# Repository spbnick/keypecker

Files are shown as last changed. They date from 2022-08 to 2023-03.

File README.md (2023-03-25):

Keypecker
=========

"Keypecker" is a device for measuring key/button switch response speed and
reliability. It uses a stepper motor to (repeatedly) move an actuator rod up
and down, and records the time from the start of the movement to a signal edge
on one or more digital inputs (channels), for each such movement (pass).

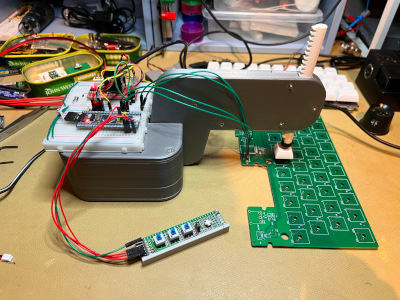
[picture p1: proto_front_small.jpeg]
Prototype front

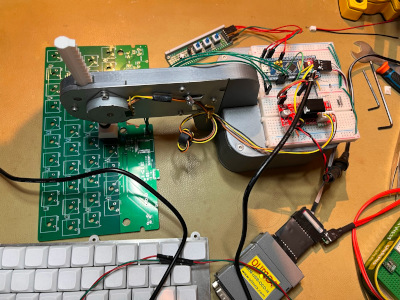
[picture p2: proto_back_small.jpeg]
Prototype back


Keypecker can be used to characterize both physical switches and response of
devices controlled by switches, provided they report events as digital signal
edges.

The device firmware is based on the Zephyr RTOS.

Keypecker is controlled via a TTL-level USART using an interactive shell with
an assortment of supported commands (including stock Zephyr commands):

```
  acquire  :Acquire a timing measurement on all enabled channels for specified
            number of passes (default 1)
  adjust   :Adjust the "current" (default), "top", or "bottom" actuator
            positions interactively
  check    :Check reliability of all-channel triggering between the top and
            bottom positions, over the specified number of passes (default is
            one)
  clear    :Clear screen.
  device   :Device commands
  devmem   :Read/write physical memory
            Usage:
            Read memory at address with optional width:
            devmem address [width]
            Write memory at address with mandatory width and value:
            devmem address <width> <value>
  down     :Move actuator down (n steps)
  get      :Get parameters
  help     :Prints the help message.
  history  :Command history.
  kernel   :Kernel commands
  measure  :Acquire a timing measurement on all enabled channels for specified
            number of passes (default 1), and output "brief" (default), or
            "verbose" results
  off      :Turn off actuator
  on       :Turn on actuator
  print    :Print the last timing measurement in a "brief" (default) or
            "verbose" format
  resize   :Console gets terminal screen size or assumes default in case the
            readout fails. It must be executed after each terminal width
            change to ensure correct text display.
  set      :Set parameters
  setup    :Make sure the actuator is on, and setup top and bottom positions
            specified number of steps (default 1) around the trigger point.
            Verify trigger with specified number of passes (default 2).
  shell    :Useful, not Unix-like shell commands.
  swing    :Move actuator back-n-forth within n steps around current position,
            until interrupted
  tighten  :Move the top and bottom positions within the specified number of
            steps (default 1) around the trigger point. Verify trigger with
            specified number of passes (default 2).
  up       :Move actuator up (n steps)
```

Here's an example session beginning at the power-on, configuring two channels
to detect pressure and release of a directly-connected key switch (Cherry MX
Brown), setting up the top and bottom positions tightly around the trigger
point, verifying that the trigger is reliable through 32 passes, and then
measuring timing of 256 passes (half down, and half up):

```
*** Booting Zephyr OS build zephyr-v3.3.0-474-geead89e7f22d ***

keypecker:~$ resize
keypecker:~$ set ch 0 down rising DOWN
keypecker:~$ set ch 1 up falling UP
keypecker:~$ setup
Actuator is off.
Move the actuator manually to a point above the trigger, and press Enter.
Press Ctrl-C to abort.

Actuator is on.
The current position is the top.
Moving one step down.
Press up and down arrow keys to move the actuator to a point below the
trigger, and press Enter.
Press Ctrl-C to abort.

Bottom position is set.
Tightening around the trigger point.
Press Ctrl-C to abort.

Setup complete.

keypecker:~$ check 32
100%

keypecker:~$ measure 256
                      #0              #1
                    DOWN              UP
-------- --------------- ---------------
    Both           Value           Value
-------- --------------- ---------------
Trigs, %            +100            +100
 Min, us           +2680           +1900
Mean, us           +2800           +1930
 Max, us           +2920           +1960
-------- --------------- ---------------
    Time        Triggers        Triggers
-------- --------------- ---------------
Both, us 0           105 0           128
         |             : |_____________:
    1900 |             : |_____________|
    1963 |             : |             :
    2026 |             : |             :
    2089 |             : |             :
    2152 |             : |             :
    2215 |             : |             :
    2278 |             : |             :
    2341 |             : |             :
    2404 |             : |             :
    2467 |             : |             :
    2530 |             : |             :
    2593 |_            : |             :
    2656 | |___________: |             :
    2719 |_____________| |             :
    2782 |             : |             :
    2845 |             : |             :
    2908 |             : |             :
-------- --------------- ---------------

keypecker:~$
```

The plus `+` signs before the measured numbers indicate overcapture
(bouncing), which is normal for physical switches.

Here's another session. This time a USB keyboard is tested. It signals the
detection of a key pressure/release on the rising edge, and the report of that
event over USB, on the falling edge, using a single wire. That is connected to
two channels - one detecting rising, another - falling edges. After the setup
of the trigger point, and a check of 16 triggers, a measurement of 256 passes
is taken:
```
*** Booting Zephyr OS build zephyr-v3.3.0-474-geead89e7f22d ***

keypecker:~$ resize
keypecker:~$ set ch 0 both rising DETECT
keypecker:~$ set ch 1 both falling REPORT
keypecker:~$ setup
Actuator is off.
Move the actuator manually to a point above the trigger, and press Enter.
Press Ctrl-C to abort.

Actuator is on.
The current position is the top.
Moving one step down.
Press up and down arrow keys to move the actuator to a point below the trigger, and press Enter.
Press Ctrl-C to abort.

Bottom position is set.
Tightening around the trigger point.
Press Ctrl-C to abort.

Setup complete.

keypecker:~$ check 16
100%

keypecker:~$ measure 256
                      #0              #1
                  DETECT          REPORT
-------- --------------- ---------------
    Both           Value           Value
-------- --------------- ---------------
Trigs, %             100             100
 Min, us            6080           12500
Mean, us           14320           20500
 Max, us           22560           28500
-------- --------------- ---------------
    Time        Triggers        Triggers
-------- --------------- ---------------
Both, us 0            49 0           204
         |___________  : |             :
    6080 |           | : |             :
    7481 |           | : |             :
    8882 |           | : |             :
   10283 |           |_: |_____________:
   11684 |        _____| |_____________|
   13085 |_______|     : |             :
   14486 |             : |             :
   15887 |             : |             :
   17288 |             : |             :
   18689 |             : |__           :
   20090 |             : |__|          :
   21491 |             : |             :
   22892 |             : |             :
   24293 |             : |             :
   25694 |             : |             :
   27095 |             : |             :
   28496 |             : |             :
-------- --------------- ---------------

keypecker:~$
```
The data shows that the events are only reported via USB at the interrupt
endpoint polling intervals (set to 9ms).

After (or during) capture the results can be output in verbose mode (somewhat
truncated for brevity):
```
keypecker:~$ print verbose
                      #0              #1
                  DETECT          REPORT
 Up/Down        Time, us        Time, us
-------- --------------- ---------------
    Down           14000           21240
      Up            6840           12540
    Down            8380           12540
      Up            9920           12540
    Down           11440           12540
      Up           12980           20520

(truncated)

    Down            9620           12960
      Up           11160           12960
    Down           12700           12960
      Up           14220           20960
-------- --------------- ---------------
      Up           Value           Value
-------- --------------- ---------------
Trigs, %             100             100
 Min, us            6240           12500
Mean, us           14400           20500
 Max, us           22560           28500
-------- --------------- ---------------
    Down           Value           Value
-------- --------------- ---------------
Trigs, %             100             100
 Min, us            6080           12500
Mean, us           10040           16870
 Max, us           14000           21240
-------- --------------- ---------------
    Both           Value           Value
-------- --------------- ---------------
Trigs, %             100             100
 Min, us            6080           12500
Mean, us           14320           20500
 Max, us           22560           28500
-------- --------------- ---------------
    Time        Triggers        Triggers
-------- --------------- ---------------
  Up, us 0            29 0           102
         |__________   : |             :
    6080 |          |  : |             :
    7481 |         _|  : |             :
    8882 |        |    : |             :
   10283 |        |____: |_____________:
   11684 |     ________| |_____________|
   13085 |____|        : |             :
   14486 |             : |             :
   15887 |             : |             :
   17288 |             : |             :
   18689 |             : |__           :
   20090 |             : |__|          :
   21491 |             : |             :
   22892 |             : |             :
   24293 |             : |             :
   25694 |             : |             :
   27095 |             : |             :
   28496 |             : |             :
-------- --------------- ---------------
Down, us 0            25 0           102
         |___________  : |             :
    6080 |           | : |             :
    7481 |          |__: |             :
    8882 |             | |             :
   10283 |           _|: |_____________:
   11684 |         _|  : |_____________|
   13085 |________|    : |             :
   14486 |             : |             :
   15887 |             : |             :
   17288 |             : |             :
   18689 |             : |__           :
   20090 |             : |__|          :
   21491 |             : |             :
   22892 |             : |             :
   24293 |             : |             :
   25694 |             : |             :
   27095 |             : |             :
   28496 |             : |             :
-------- --------------- ---------------
Both, us 0            49 0           204
         |___________  : |             :
    6080 |           | : |             :
    7481 |           | : |             :
    8882 |           | : |             :
   10283 |           |_: |_____________:
   11684 |        _____| |_____________|
   13085 |_______|     : |             :
   14486 |             : |             :
   15887 |             : |             :
   17288 |             : |             :
   18689 |             : |__           :
   20090 |             : |__|          :
   21491 |             : |             :
   22892 |             : |             :
   24293 |             : |             :
   25694 |             : |             :
   27095 |             : |             :
   28496 |             : |             :
-------- --------------- ---------------

keypecker:~$
```

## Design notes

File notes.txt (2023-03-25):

Commands:
* Disable motor control
	"off"
* Enable motor control
	"on"
* Register the current position as fully pressed (only when enabled)
	"location pressed"
* Register the current position as fully released (only when enabled)
	"location released"
* Move motor down 1 or n steps (only when enabled)
	"down [n]"
* Move motor up 1 or n steps (only when enabled)
	"up [n]"
* Specify how to detect a pressure event (which edge)
	"sense pressure rising"
* Specify how to detect a release event (which edge)
	"sense release falling"

State:
	off
	on
		not moving
		moving

---
We need to be able to tell the actuator which position to go to, and with
which speed. We should also be able to give new instructions before the
previous ones were completed. Finally we should be able to wait until each
instruction is either completed, or aborted/superseded.

We can only have one task at a time, so it makes sense to have one state to
keep. We could have a completion/interruption callback attached to the state.
Then we could have an API that would lock that state, and call interruption
callback when we give it a new task. The timer function would strive to
execute the task and call completion callbacks.
---
TODO: Add an emergency stop button.
---
How about we have a semaphore that's taken for moving the actuator and
returned when moving is done, or aborted?
---

				DISABLED	ENABLED		MOVING
kp_act_get_status		return		return		return
kp_act_set_status(false->true)	-> ENABLED	noop		noop
kp_act_set_status(true->false)	noop		-> DISABLED	-> DISABLED (ABORTED)
kp_act_get_pos			return(last)	return		wait -> return
kp_act_move_(to,by)		return DISABLED	MOVE, return	wait, MOVE, return
kp_act_move_abort		return		return		ABORT, return

MOVE LOCK?

What are we trying to do?

We want to make sure only one thread has control over the actuator, one "procedure".
The command takes control, does its job (moving the actuator,
calibrating/aiming, running a test, etc.), and then releases control.

We want to be able to cancel a command.
	- So, if we want the actuator module to go and do something for us by
	  itself, we need to be able to abort that long-running task. That
	  means we would need to have two-level abort: one level for the
	  actuator library, and one for the command.
	- However, even if we would e.g. try to control the actuator fully, in
	  the command itself, we would still need to have two-level abort: one
	  for the sleep intervals, when we're waiting for the next step, and
	  one for the command itself. So, perhaps, we could live with two
	  levels.
	- E.g. implement locking "actuator control", and provide a function to
	  break that lock, which would make all the functions trying to
	  continue executing with that lock, abort.
We want to be able to reset the robot completely.
	- a simple controller reset would be fine,
	as that would immediately bring "enable" down,
	and release control of the actuator

OK, how about we return a value when enabling the actuator, then use that value
when locking the actuator use, which would return another value.

        off --[on]--> on --[hold]--> held --[move]--> moving
         ^            |^              |^                |
         `----[off]---'`--[release]---'`---[finish]-----'
         ^             ^              |^                |
         `-------------|----[off]-----'`----[abort]-----'
         ^             |                                |
         |             `-------------------[release]----'
         |                                              |
         `-----------------------------------[off]------'

	off --[on: power]--> on --[hold(power): handle]--> held --
	--[move about, read position, etc. (handle)]--> moved --[finish]-->
	held --[release(handle)]-> on --[off(power)]

extern kp_act_power kp_act_on(void);
extern kp_act_pos kp_act_locate(kp_act_power power);
extern kp_act_handle kp_act_hold(kp_act_power power);
extern kp_act_rc kp_act_move(kp_act_handle handle, bool absolute, kp_act_pos pos);
extern void kp_act_abort(kp_act_handle handle);
extern void kp_act_release(kp_act_handle handle);
extern void kp_act_off(kp_act_power power);

Should another module be able to turn off the power without knowing the "power"?
Should we perhaps make the "power" value internal to the kp_act module?
---
What are we trying to do?

* To make it safe to use the actuator from separate threads on a multi-core
  system? Soo...
	* Should a thread be able to "turn on" the actuator if it's already
	  turned on by another thread? The same thread?
	* Should a thread be able to turn off the actuator if it's turned on
	  by another thread?
	* Should a thread be able to cancel a movement requested by another
	  thread?
	  	- We need this for aborting shell commands
	* Should we perhaps provide strongest guarantees for thread
	  separation, and let threads decide how much control they want to
	  share with other threads?
	* There's a difference between protecting threads and giving out
	  the users unique values to handle power ons and actuator movements.

* To make sure that absolute position values are not used across power-ons?
---
We have a single lock for the complete internal state.
We hold the lock while moving to prevent the power being turned off and
another move competing with our move.
We need to be able to abort a move.
	To be able to do that we need to verify that the correct power is
	supplied to the function. To access that we need to acquire a lock.

We need to figure out which pieces of internal state we need when, and how
consistent we need them.
---
Possible operations and exclusivity

init	locate	on	abort
		off
		move

TODO: Check that the actuator module is initialized in all its functions.
	- done
TODO: Consider adding a function checking if a position is valid for a power.
	- not needed anymore, as we don't have "power"

We need to keep all the state locked at first, when starting the movement, and
then unlock the termination flag, so that abortion can happen.

The abortion function needs to verify if the power is on, and if the movement
is running, and then abort.

Timer function:
	With locked state:
		If power is off
			Give movement semaphore
			Stop
		If abort is requested
			Reset abort flag
			Give movement semaphore
			Stop
		Move next step

Move function:
	With locked movement:
		Lock state
		Setup timer
		Unlock state
		Take movement semaphore

We need to prevent two move functions being called at once
---

OK, how do we organize running interactive shell commands?

Shell commands are assigned a kp_cmd_* function each.
The kp_cmd_* function reads and validates arguments, and invokes a library
function specifying which function to run for the actual command body, and
returns with status zero.

The library function sets a shell bypass function which interprets input
sequences, and schedules executing the specified function with another thread,
then returns.

The other thread runs the function, then removes the shell bypass function, to
give control back to the shell.

Can we use setjmp/longjmp to keep the body of actual command inside the
kp_cmd_* function?

So something like this would be nice:

kp_cmd_blah(shell, argc, argv)
{
	/* Parse and validate args */
	...
	/* Install shell bypass, return control to shell */
	YIELD_TO_SHELL;
	/* Run inside separate thread, outside shell */
	/* Return to the thread, which removes shell bypass */
	DONE;
}

Likely won't work, as that would be jumping from one thread's stack to another
thread's stack.

What if instead we had a single generic function save the arguments we're
passed, install the bypass function, schedule execution of the actual
command in another thread, and return to shell. Another thread calls the
function, and then removes the bypass function when it returns.

Or perhaps we can have a macro which installs the bypass function, stores the
current command function address and the arguments and schedules the function
execution in another thread, and returns to the shell. Then another thread
calls the same function but with e.g. a special command name, or maybe a
special shell pointer, and that makes the macro proceed with the function
execution instead. This seems like a good idea.

We can even put the argument validation in front of that macro, so it exits
early. It would be OK to validate and parse arguments again.

How do we implement command termination with Ctrl-C?
OK the input-reading function could scan the input for the Ctrl-C sequence,
and then somehow terminate the command. Maybe the command could pass a
termination callback to kp_shell_cmd_schedule, and that callback would abort
the movement with kp_act_abort(), and set a variable specifying that the
command was aborted?

TODO: Define the move timer inside the move function
	- perhaps won't be needed if we use a timer peripheral for driving
---
Control key inputs:

0x03 - Ctrl-C
0x04 - Ctrl-D
0x1b 0x5b 0x41 - Up
0x1b 0x5b 0x42 - Down
0x1b 0x5b 0x43 - Right
0x1b 0x5b 0x44 - Left
0x0d - Enter
---

So, how should we record our pressure/report times? We can find out which step
triggers the report by calibrating/aiming. Then, before we request moving the
actuator the required number of steps to traverse the report point, in either
direction, we register the current time and the type of the movement
(press/release). After the movement is done, we wait for the report (timestamp
message from GPIO ISR on a message queue?).

OK, we can get a sequence of movement and trigger timestamp pairs in our
testing routine. Now what do we do with that?

We need tests for:
	Detection/report latency for both press and release events
		Take timestamp, move as fast as possible, take signal
		timestamp
		Repeat a bunch of times
		Calculate and report latency minimum, maximum, and averages
	Detection/report reliability/debouncing of both press and release
		Move the actuator with the specified speed
		Wait some time
		Check how many signals we get
		Repeat a bunch of times with varying speed and swing
---
Use Ctrl-C to abort exactly where you are, and Enter to stop nicely (e.g.
return to the start point of "swing").
	- done

FIXME: Swing of a powered-off actuator requires Ctrl-C to exit
	- fixed with a dirty trick
---
Trying to add a shell input reading function

shell_thread
    shell_process
        switch (shell->ctx->state) {
        case SHELL_STATE_ACTIVE:
            shell_process
                state_collect
                    execute
                        exec_cmd
        }

Can we avoid the extra thread?

Nope, we gotta keep processing input

Actually, maybe we can have that special function poll for the RXRDY signal

Posted the failure on GitHub, waiting for advice/comments, continuing with the
hack for now.
---
So, we need to have an STM32 timer started by a rising edge of the "step"
signal, and a capture triggered by the signal we're interested in. If we want
to have more than one input signal, we need more than one timer, or at least
more than one channel. Gotta check that. OK, looks like we can have several
inputs and registers to register the timing. Great!

Now we gotta figure out which pins are available for which.
OK, the pins are listed on page 179 of RM. Default mapping:

CH1:	PA8
CH2:	PA9
CH3:	PA10
CH4:	PA11
ETR:	PA12

Next we'll need to figure out if more configuration is needed on those.
It's likely that it is needed, since there's an USART on PA8-9 by default.

TODO:
* Make sure USART doesn't interfere with the timer
	- switch the pins to "alternate function push-pull" somehow
	- DONE!
* Make the timer start counting and overflow when movement starts
	- Done!

OK, PA11 and PA12 are out of the game, as they're used by USB for D- and D+.
So, we'll have to do with PA8, PA9, PA10. We could use PA10 for trigger, and
PA8 and PA9 for signaling.

Ah, it looks like only the first and the second input channels are connected
to the slave mode controller and can trigger the counter. Well, channel three
can do that too through a XOR gate with all other inputs, but we don't want to
mess with that. So it would be the other way around:

PA8:	Trigger
PA9:	Capture channel 1
PA10:	Capture channel 2

When starting the capture you can specify which channels/how to capture.
Then you can call a function requesting the result when/if it's ready.
---
TODO: Add support for awaiting overcapture for a bounce period
	- Done!
TODO: Retrieve the timer clock rate, like the PWM driver does
      (drivers/pwm/pwm_stm32.c)
---
We can simplify the actuator's interface if we keep the current power
module-side and don't force the caller remember and to provide it.

However, we would still need to expose and to use it for relative movements.
So, maybe we better get rid of the tracked power on altogether.

TODO: Rename kp_pos_* to kp_act_pos_*
	- done
TODO: Initialize GPIO pins outside module initializations
---
So, we need to support a bounce period for capture. It should be separate for
each channel, and should start immediately after the channel is captured.

We should wait for at least the specified period before concluding the
capture, but we can wait for longer, if we're waiting for other channels.

The maximum time we can wait for a channel capture should therefore be the
maximum timer period minus the bounce period.

It seems we need to have a "finish" timer that is started once the last
channel is captured. Should we adjust the auto-reload register then, to point
to the time we need to stop?

We can take the largest captured value across all channels, add the bounce
time to that, and write it to the ARR register.
---
We don't have to maintain the exact minimum bounce time and could take a
little longer. Therefore, we could take our time setting up the timer for
measuring the bounce period.

Once we got all the channels captured, we could stop the timer momentarily,
and shorten the ARR to the current time plus the bounce period, provided that
doesn't exceed the maximum capture time.

Wait, that doesn't let us finish the capture early, right after the timeout,
in case there was nothing captured.

What if we set ARR to the timeout initially, then when the first update
interrupt comes, we shorten the ARR to the bounce time, and on the second
update interrupt we finish.

Eh, maybe let's just keep it this way for now. Timeout of all channels is an
unlikely event, and the bounce time is usually short.

TODO: Use a signal generator to verify bouncing under timer resolution is
      captured. We can use a scope and a real switch for that.
TODO: Use a signal generator to verify bounce-time signals are
      considered timeouts. We can use a scope and a real switch for that.

---
What are we looking for?
The two steps: one immediately before the trigger and one at the trigger. We
might not be able to find them, because they will be too close to the trigger
point. Then we need to find the minimum range of steps where the trigger
happens reliably.

Perhaps we could do each transition a few times to make sure it's reliable,
and back off, it's not.

So, we could have three results for each transition: not triggering,
triggering, triggering unreliably.

We start without the assumption whether the current top-bottom range is
reliably triggering. We test it first, and then proceed.

function check_range(top, bottom, tries):
	for i in range(0, tries):
		move to top
		start capture
		move to bottom
		finish capture
		record result
	return triggered/not triggered/inconclusive

assert kp_act_pos_top < kp_act_pos_bottom
top = None
bottom = None
middle = None
next_top = kp_act_pos_top
next_bottom = kp_act_pos_bottom

forever:
	triggered = check_range(next_top, next_bottom, 3)
	if not triggered:
		# If we tried the top half
		if next_bottom == middle:
			# Try the bottom half
			next_top = middle
			next_bottom = bottom
			continue
		break
	top = next_top
	bottom = next_bottom
	if bottom - top <= 1:
		break
	middle = (top + bottom) / 2
	# Try the top half
	next_top = top
	next_bottom = middle

if not (top and bottom):
	error("No reliable trigger between top and bottom, not narrowed")

if top == kp_act_pos_top and bottom == kp_act_pos_bottom:
	info("The top and bottom positions are already as close as "
		"possible to the trigger point")
kp_act_pos_top = top
kp_act_pos_bottom = bottom

---
We need to handle the situation where we hit exactly the trigger point in one
of the steps and the trigger becomes unstable. We could rectify that by moving
further from the origin boundary. E.g. half way again to the opposite
boundary.
---
So, we need one final push to get actual use out of the device: measuring
timing. We need to make the "measure" command output timing of every pass
(optional), plus the summary (mandatory), for each channel: minimum time,
maximum time, and the average (which one, though? arithmetic mean for the
start? maybe mode as well, rounded to ms?).

TODO: Make k_poll_event_init() accept NULL object with K_POLL_TYPE_IGNORE
TODO: Consider making K_POLL_TYPE_* into an enum for safety.
TODO: Unify format of shell command help messages, including argument
      placement
TODO: Consider testing how fast the keyboard can detect key pressures / how
      many it misses at which speed.
TODO: Figure out if we should check that the top position doesn't also hit the
      trigger.
---
So, something like "measure [<passes> [brief|verbose]]"

And verbose output looking like this:

                      #0              #1
                  DETECT          REPORT
-------- --------------- ---------------
 Up/Down        Time, us        Time, us
-------- --------------- ---------------
    Down           12003           23322
      Up           11449           22334
    Down           12003           23322
      Up           11449           22334
    Down           12003           23322
      Up           11449           22334
    Down           12003           23322
      Up           11449           22334
-------- --------------- ---------------
 Up/Down     Triggers, %     Triggers, %
-------- --------------- ---------------
      Up             100             100
    Down             100             100
 Up&Down             100             100
-------- --------------- ---------------
 Up/Down    Time max, us    Time max, us
-------- --------------- ---------------
      Up           11449           22334
    Down           12003           23322
 Up&Down           11755           22802
-------- --------------- ---------------
 Up/Down    Time min, us    Time min, us
-------- --------------- ---------------
      Up           11449           22334
    Down           12003           23322
 Up&Down           11755           22802
-------- --------------- ---------------
 Up/Down   Time mean, us   Time mean, us
-------- --------------- ---------------
      Up           11449           22334
    Down           12003           23322
 Up&Down           11755           22802
-------- --------------- ---------------
 Up/Down   Time mode, ms   Time mode, ms
-------- --------------- ---------------
      Up              11              22
    Down              12              23
 Up&Down              11              22
-------- --------------- ---------------
Time, us        Triggers        Triggers
-------- --------------- ---------------
    Down 0            50 0            50
   11000 |:___           |              
   11200 |    :_         |              
   11400 |   ___:        |              
   11600 | _:            |              
   11800 |:              |:___          
   12000 |               |    :_        
   12200 |               |   ___:       
   12400 |               | _:           
   12600 |               |:             
-------- --------------- ---------------
      Up 0            50 0            50
   11000 |:___           |              
   11200 |    :_         |              
   11400 |   ___:        |              
   11600 | _:            |              
   11800 |:              |:___          
   12000 |               |    :_        
   12200 |               |   ___:       
   12400 |               | _:           
   12600 |               |:             
-------- --------------- ---------------
    Both 0            50 0            50
         |___	       : |
   11000 |   |         : |              
   11200 |    |_       : |              
   11400 |   ___|      : |              
   11600 | _|          : |              
   11800 ||___         : |:___          
   12000 |    |________: |    :_        
   12200 |         ____| |   ___:       
   12400 |   _____|    : | _:           
   12600 |__|          : |:             
   12600 |             : |:             
   12600 |             : |:             
   12600 |             : |:             
   12600 |             : |:             
   12600 |             : |:             
   12600 |             : |:             
   12600 |             : |:             
-------- --------------- ---------------

Ah, would be nice, but we can't use Unicode characters, because printf equates
bytes to characters. Let's just use words.

FIXME: First capture fails sometimes

A shorter output without breakdown for direction could look like this,
perhaps:

-------- --------------- ---------------
  Metric           Value           Value
-------- --------------- ---------------
Trigs, %             100             100
 Min, us           11449           22334
 Max, us           11755           23322
Mean, us           11623           22750
Mode, us           11623           22750

TODO: Output channel legends at the end of a long output.
TODO: Use TIM1 ETR input for triggering, and enable two more channels

---
TODO: Consider moving all GPIO configuration into main(), as it's the place
	where everything is connected.

So, we still have to wait for a bounce period, when we're moving, even though
we're not capturing any channels, because the bounce from the previous move
could trigger the capture of the next move.

The question is whether we should do the waiting in the capture module or in
the kp_sample() function. In principle, capture doesn't really have to know
anything about moving. It doesn't even have to be invoked along with movement.

OTOH, the kp_sample() function knows exactly when the actuator, and should
expect the contact to bounce, so it is kp_sample() which should take care of
that.

Still OTOH, there's no support for polling for a timer/sleep, so we would have
to have some thread wait that bounce period and then give a semaphore in order
for the poll in kp_sample() to work out that the bounce period has ended.
Perhaps instead we could make the capture module do this for us with certain
inputs. For example, say that if we're invoking a capture with all channels
disabled, it will just wait for the bounce period. And if the code doesn't
want to do that, it should just not invoke the capture. Seems like a good
idea!

Ah, we have a problem: if we're not capturing any channels, we don't know how
long it takes to reach the trigger point, and so just waiting for a bounce
period doesn't work. It might be too short, because it only counts from the
moment of the first capture.

So perhaps we need to tell the users (ourselves :D) that you should have at
least one channel enabled both ways. And as a protection against this
situation we should perhaps make the capture module wait for the full timeout
plus bounce time when capturing with no channels enabled.

---
TODO: Do not waste capture memory, use linear array of capture results with
      dynamic striding according to the number of channels enabled.
      - done
TODO: Do not capture passes (directions) without channels enabled. Adjust
      statistics and histogram generation accordingly.
      - done, most likely
TODO: Store capture parameters and results in a global state, and add a
      separate command outputting previous results according to the same
      output option as taken by the "measure" command. Call it e.g. "display".
      - done
TODO: Add shorter command aliases: "speed", "ch" "adj", "timeout", "bounce".
TODO: Add "setup" command, which sets and tightens the boundaries.
	- done
TODO: Make the "tighten" command smarter and more reliable.
TODO: Use a timer for driving the actuator.
TODO: Make commands accept shortened, but unique string argument values
FIXME: Maximum down times are longer with "measure" without "verbose"
       argument.
	- seems to be gone now

---
OK, assuming that (^^^) is the bounce that gets captured as another rising edge,
and makes the times longer, why is that only captured without verbose output?

Could this be due to interrupt status/timing and the ISR reading the registers
affecting the value written?

OK, so what's the difference? Timing doesn't seem to be it, it's the output to
the shell that makes it behave better in particular, it seems.

So, the hardware manages to sometimes record a bounce, if we don't output to
the shell. Could it be the interference when the serial port is not driven?

TODO: Use a timer for movement
TODO: Implement separate output command
	- done
TODO: Raise the debug pin when a long time is captured on one of the channels
	- not needed, now that the capture discrepancy seems to be fixed
TODO: Figure out why the actuator stops working when the driver board/heatsink
      is flexed
TODO: Refer to enum kp_cap_dir as "Capture direction set"
	- done

Should we count passes which don't capture any channels?
	For tightening?
	For checking?
	For measuring?
Should we actually consider going both ways a "pass" for simplicity?
	If yes, should it be always first down, then up, for simplicity, or
	could it be either?
		Seems like that should be the solution.
		However, this would limit our testing to go always in two
		specific directions, and that may prevent some bugs from
		reproducing.
		So perhaps it's better to keep giving the number of passes.
---
sample - collect -.
                   :--- measure
         display -'

kp_measurement_acquire
kp_measurement_print
kp_measurement_make

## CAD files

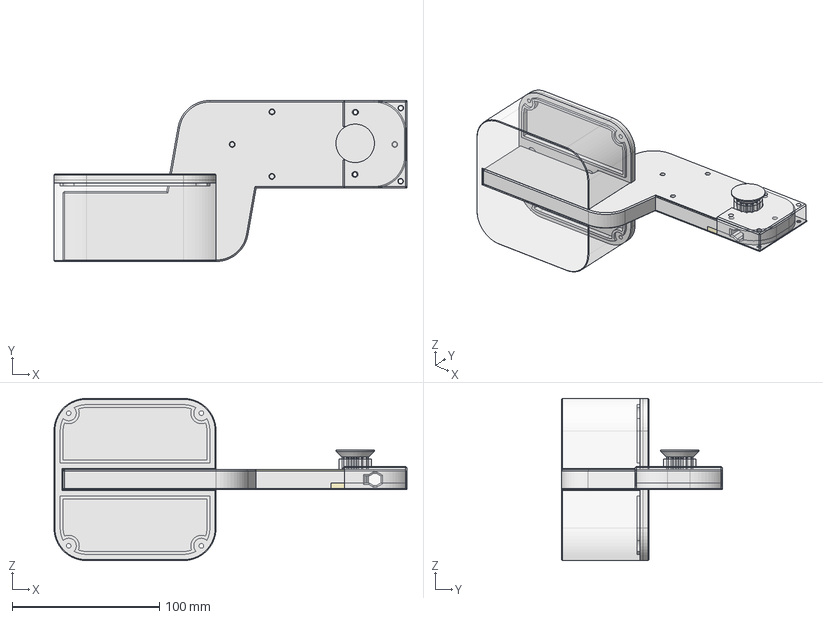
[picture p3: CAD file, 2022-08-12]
keypecker.FCStd
240.0 x 109.5 x 110.2 mm
gear_pusher_old_v2
gear_pusher
motor_heatsink_old
horizontal_arm_body_old
motor_heatsink
weight_body
weight_cap_body
gear
gear_push_guide
ShapeBinder014
arm_slice_1
arm_slice_2
Slice.2

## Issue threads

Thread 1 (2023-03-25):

Support turning off actuator after a configured timeout

spbnick, 2023-03-25:
Keeping the actuator stepper energized requires a lot of power (relatively) and produces a lot of heat, both in the driver and the stepper. Support configuring a timeout after which the actuator is turned off.

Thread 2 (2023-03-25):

Support saving configuration

spbnick, 2023-03-25:
It would be useful to save a lot of configuration parameters, such as channel configuration, timeouts and speeds. Implement saving and loading one or more configurations to/from flesh, using shell commands. Support a command for resetting the device to default configuration. Consider supporting loading (a certain) configuration on boot.

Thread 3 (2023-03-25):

Design the circuit in KiCAD, and produce a bunch of populated PCBs

spbnick, 2023-03-25:
Currently the circuit only exists on a breadboard, in the single prototype. Design a proper (simplified) circuit, possibly using/supporting knock-off STM32F103C8T6 chips, and an actual PCB to be mounted onto the device.

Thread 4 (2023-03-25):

Generalize mechanical and electromechanical design

spbnick, 2023-03-25:
At the moment the design is tuned to the particular piece of stepper heatsink piece I managed to make, and the particular stepper, with particular gear on its shaft. Consider finding a suitable, widely-available (but light) stepper, and redesigning everything around it.

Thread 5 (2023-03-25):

Add emergency stop button

spbnick, 2023-03-25:
Incorporate an emergency stop button into the design. Either a power-cut (preferred), or just the MCU reset button.

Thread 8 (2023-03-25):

Support faster actuator movement with PgUp/PgDn

spbnick, 2023-03-25:
At the moment actuator movement can only be controlled with Up/Down arrow keys, moving the actuator by one step. Support moving the actuator by e.g. ten steps with PgUp/PgDn keys. The problem there are rather involved control sequences coming from the terminal for them, which are hard to parse correctly.

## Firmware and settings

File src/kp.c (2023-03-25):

/** @file
 *  @brief Keypecker main entry point
 */

/*
 * Copyright (c) 2022 Nikolai Kondrashov
 *
 * SPDX-License-Identifier: GPL-2.0-or-later
 */

#include "kp_cap.h"
#include "kp_act.h"
#include "kp_shell.h"
#include "kp_input.h"
#include "kp_sample.h"
#include "kp_meas.h"
#include "kp_misc.h"
#include <stm32_ll_tim.h>
#include <assert.h>
#include <stdlib.h>
#include <sys/types.h>
#include <zephyr/kernel.h>
#include <zephyr/device.h>
#include <zephyr/logging/log.h>
#include <zephyr/drivers/clock_control/stm32_clock_control.h>
#include <zephyr/drivers/gpio.h>
#include <zephyr/drivers/uart.h>
#include <zephyr/shell/shell.h>

/** Devicetree node identifier for the actuator's GPIO port */
#define KP_ACT_GPIO_NODE DT_NODELABEL(gpiob)
/** Devicetree node identifier for the debug GPIO port */
#define KP_DBG_GPIO_NODE DT_NODELABEL(gpioa)

/** Devicetree node identifier for the timer */
#define KP_TIMER_NODE DT_NODELABEL(timers1)

/** The actuator GPIO port device */
static const struct device *kp_act_gpio = DEVICE_DT_GET(KP_ACT_GPIO_NODE);

/** The debug GPIO port device */
static const struct device *kp_dbg_gpio = DEVICE_DT_GET(KP_DBG_GPIO_NODE);

/** The pin for update interrupt debugging */
const gpio_pin_t kp_dbg_pin_update = 3;

/** The base pin for channel capture debugging */
const gpio_pin_t kp_dbg_pin_ch_base = 4;

/** Actuator speed, 0-100% */
static uint32_t kp_act_speed = 100;

/** Top actuator position */
static int32_t kp_act_pos_top = KP_ACT_POS_INVALID;

/** Bottom actuator position */
static int32_t kp_act_pos_bottom = KP_ACT_POS_INVALID;

/** Execute the "on" command */
static int
kp_cmd_on(const struct shell *shell, size_t argc, char **argv)
{
	ARG_UNUSED(argc);
	ARG_UNUSED(argv);
	if (!kp_act_on()) {
		shell_info(shell, "Actuator is already on");
	}
	return 0;
}

SHELL_CMD_REGISTER(on, NULL, "Turn on actuator", kp_cmd_on);

/** Execute the "off" command */
static int
kp_cmd_off(const struct shell *shell, size_t argc, char **argv)
{
	ARG_UNUSED(argc);
	ARG_UNUSED(argv);
	if (kp_act_off()) {
		kp_act_pos_top = KP_ACT_POS_INVALID;
		kp_act_pos_bottom = KP_ACT_POS_INVALID;
	} else {
		shell_info(shell, "Actuator is already off");
	}
	return 0;
}

SHELL_CMD_REGISTER(off, NULL, "Turn off actuator", kp_cmd_off);

/**
 * Parse a non-negative number from a string.
 *
 * @param str	The string to parse the number from.
 * @param pn	Location for the number parsed from the string.
 *
 * @return True if the string was representing a valid non-negative number,
 * 		false otherwise.
 */
static bool
kp_parse_non_negative_number(const char *str, long *pn)
{
	char *end;
	long n;
	n = strtol(str, &end, 10);
	if (*str == '\0' || *end != '\0' || n < 0 || n == LONG_MAX) {
		return false;
	}
	*pn = n;
	return true;
}

/** Execute the "up [steps]" command */
static int
kp_cmd_up(const struct shell *shell, size_t argc, char **argv)
{
	long steps;
	enum kp_act_move_rc rc;
	if (argc >= 2) {
		if (!kp_parse_non_negative_number(argv[1], &steps)) {
			shell_error(shell, "Invalid number of steps: %s",
					argv[1]);
			return 1;
		}
	} else {
		steps = 1;
	}
	rc = kp_act_move_by(-steps, kp_act_speed);
	switch (rc) {
		case KP_ACT_MOVE_RC_OFF:
			shell_error(shell, "Actuator is off, stopping");
			break;
		case KP_ACT_MOVE_RC_ABORTED:
			shell_error(shell, "Aborted");
			break;
		default:
			break;
	}
	return rc != KP_ACT_MOVE_RC_OK;
}

SHELL_CMD_ARG_REGISTER(up, NULL, "Move actuator up (n steps)",
			kp_cmd_up, 1, 1);

/** Execute the "down [steps]" command */
static int
kp_cmd_down(const struct shell *shell, size_t argc, char **argv)
{
	long steps;
	enum kp_act_move_rc rc;
	if (argc >= 2) {
		if (!kp_parse_non_negative_number(argv[1], &steps)) {
			shell_error(shell, "Invalid number of steps: %s",
					argv[1]);
			return 1;
		}
	} else {
		steps = 1;
	}
	rc = kp_act_move_by(steps, kp_act_speed);
	switch (rc) {
		case KP_ACT_MOVE_RC_OFF:
			shell_error(shell, "Actuator is off, stopping");
			break;
		case KP_ACT_MOVE_RC_ABORTED:
			shell_error(shell, "Aborted");
			break;
		default:
			break;
	}
	return rc != KP_ACT_MOVE_RC_OK;
}

SHELL_CMD_ARG_REGISTER(down, NULL, "Move actuator down (n steps)",
			kp_cmd_down, 1, 1);

/**
 * Process input from the bypassed shell of a scheduled command.
 *
 * @param shell Shell instance.
 * @param data  Raw data from transport.
 * @param len   Data length.
 */
static void
kp_input_bypass_cb(const struct shell *shell, uint8_t *data, size_t len)
{
	ARG_UNUSED(shell);
	kp_input_recv(data, len);
}

/** Execute the "swing steps" command */
static int
kp_cmd_swing(const struct shell *shell, size_t argc, char **argv)
{
	/* Poll event indices */
	enum {
		EVENT_IDX_INPUT = 0,
		EVENT_IDX_ACT_FINISH_MOVE,
		EVENT_NUM
	};
	long steps;
	enum kp_act_move_rc rc;
	enum kp_input_msg msg;
	int32_t start_pos;
	struct k_poll_event events[EVENT_NUM];

	/* Parse arguments */
	assert(argc == 2 || argc == (size_t)SSIZE_MAX + 2);
	if (!kp_parse_non_negative_number(argv[1], &steps) || steps == 0) {
		shell_error(shell, "Invalid number of steps: %s",
				argv[1]);
		return 1;
	}

	/* Check for power */
	if (kp_act_is_off()) {
		shell_error(shell, "Actuator is off, aborting");
		return 1;
	}

	/* Return to the shell and restart in an input-diverted thread */
	KP_SHELL_YIELD(kp_cmd_swing, kp_input_bypass_cb);
	kp_input_reset();

	/* Remember the start position */
	start_pos = kp_act_locate();

	/* Initialize events */
	kp_input_get_event_init(&events[EVENT_IDX_INPUT]);
	kp_act_finish_move_event_init(&events[EVENT_IDX_ACT_FINISH_MOVE]);

	/* Move */
	shell_print(shell, "Swinging, press Enter to stop, Ctrl-C to abort");
	rc = kp_act_move_by(steps / 2, kp_act_speed);
	bool finished = false;
	while (rc == KP_ACT_MOVE_RC_OK && !finished) {
		bool moved = false;
		steps = -steps;
		kp_act_start_move_by(steps, kp_act_speed);
		while (rc == KP_ACT_MOVE_RC_OK && !moved) {
			while (k_poll(events, ARRAY_SIZE(events),
				      K_FOREVER) != 0);

			if (events[EVENT_IDX_INPUT].state) {
				while (kp_input_get(&msg, K_FOREVER) != 0);
				if (msg == KP_INPUT_MSG_ABORT) {
					kp_act_abort();
				} else if (msg == KP_INPUT_MSG_ENTER) {
					finished = true;
				}
			}

			if (events[EVENT_IDX_ACT_FINISH_MOVE].state) {
				rc = kp_act_finish_move(K_FOREVER);
				moved = (rc == KP_ACT_MOVE_RC_OK);
			}

			/* Reset event state */
			for (size_t i = 0; i < ARRAY_SIZE(events); i++) {
				events[i].state = K_POLL_STATE_NOT_READY;
			}
		}
	}

	if (finished && rc == KP_ACT_MOVE_RC_OK) {
		/* Return to the start position */
		rc = kp_act_move_to(start_pos, kp_act_speed);
	}

	/* Report error, if any */
	if (rc == KP_ACT_MOVE_RC_ABORTED) {
		shell_error(shell, "Aborted");
	} else if (rc == KP_ACT_MOVE_RC_OFF) {
		shell_error(shell, "Actuator is off, stopping");
	}
	return rc != KP_ACT_MOVE_RC_OK;
}

SHELL_CMD_ARG_REGISTER(swing, NULL,
			"Move actuator back-n-forth within n steps around "
			"current position, until interrupted",
			kp_cmd_swing, 2, 0);

/**
 * Adjust the value of the specified actuator position variable interactively.
 *
 * @param ppos	Location for the position variable to adjust.
 * 		If NULL, or if the value is invalid, the adjustment starts
 * 		from the current position. If NULL, the final position is not
 * 		stored. Only written to after a successful adjustment.
 * @param min	The minimum position to limit adjustment to, less than or
 *		equal to max. Or KP_ACT_POS_INVALID, meaning KP_ACT_POS_MIN.
 * @param max	The maximum position to limit adjustment to, greater than or
 *		equal to min. Or KP_ACT_POS_INVALID, meaning KP_ACT_POS_MAX.
 * @param speed	The speed with which to move, 0-100%.
 *
 * @return A movement result code, excluding KP_ACT_MOVE_TIMEOUT.
 */
static enum kp_act_move_rc
kp_adjust(int32_t *ppos, int32_t min, int32_t max, uint32_t speed)
{
	int32_t pos = (ppos == NULL) ? KP_ACT_POS_INVALID : *ppos;
	enum kp_act_move_rc rc;
	enum kp_input_msg msg;

	if (!kp_act_pos_is_valid(min)) {
		min = KP_ACT_POS_MIN;
	}
	if (!kp_act_pos_is_valid(max)) {
		max = KP_ACT_POS_MAX;
	}

	assert(min <= max);

	if (!kp_act_pos_is_valid(pos)) {
		pos = kp_act_locate();
		if (!kp_act_pos_is_valid(pos)) {
			return KP_ACT_MOVE_RC_OFF;
		}
	}

	/* Bring the variable within the allowed range */
	pos = CLAMP(pos, min, max);

	/* Move to the position in the variable */
	rc = kp_act_move_to(pos, speed);
	if (rc != KP_ACT_MOVE_RC_OK) {
		return rc;
	}

	/* Adjust the position within the allowed range until confirmed */
	do {
		while (kp_input_get(&msg, K_FOREVER) != 0);
		if (msg == KP_INPUT_MSG_UP || msg == KP_INPUT_MSG_DOWN) {
			pos += (msg == KP_INPUT_MSG_DOWN) ? 1 : -1;
			pos = CLAMP(pos, min, max);
			rc = kp_act_move_to(pos, speed);
			if (rc != KP_ACT_MOVE_RC_OK) {
				return rc;
			}
		} else if (msg == KP_INPUT_MSG_ABORT) {
			return KP_ACT_MOVE_RC_ABORTED;
		}
	} while (msg != KP_INPUT_MSG_ENTER);

	/* Output the new position, if requested */
	if (ppos != NULL) {
		*ppos = pos;
	}

	return KP_ACT_MOVE_RC_OK;
}

/** Execute the "adjust" command */
static int
kp_cmd_adjust(const struct shell *shell, size_t argc, char **argv)
{
	int32_t start_pos;
	const char *arg;
	int32_t min = KP_ACT_POS_MIN;
	int32_t max = KP_ACT_POS_MAX;
	int32_t *ppos = NULL;
	enum kp_act_move_rc rc;

	ARG_UNUSED(argc);
	ARG_UNUSED(argv);

	/* Get the start position and check for power */
	if (!kp_act_pos_is_valid(start_pos = kp_act_locate())) {
		shell_error(shell, "Actuator is off, aborting");
		return 1;
	}

	/* Return to the shell and restart in an input-diverted thread */
	KP_SHELL_YIELD(kp_cmd_adjust, kp_input_bypass_cb);
	kp_input_reset();

	/* Parse the optional argument */
	if (argc > 1) {
		arg = argv[1];
		if (kp_strcasecmp(arg, "top") == 0) {
			ppos = &kp_act_pos_top;
			if (kp_act_pos_is_valid(kp_act_pos_bottom)) {
				max = kp_act_pos_bottom - 1;
			}
		} else if (kp_strcasecmp(arg, "bottom") == 0) {
			if (kp_act_pos_is_valid(kp_act_pos_top)) {
				min = kp_act_pos_top + 1;
			}
			ppos = &kp_act_pos_bottom;
		} else if (kp_strcasecmp(arg, "current") != 0) {
			shell_error(
				shell,
				"Invalid position name "
				"(current/top/bottom expected): %s",
				arg
			);
			return 1;
		}
	}

	/* Adjust */
	shell_print(shell,
		    "Press up and down arrow keys to move the actuator.");
	shell_print(shell, "Press Enter to stop, Ctrl-C to abort.");
	rc = kp_adjust(ppos, min, max, kp_act_speed);

	/* Report error, if any */
	if (rc == KP_ACT_MOVE_RC_ABORTED) {
		shell_error(shell, "Aborted");
		return rc;
	} else if (rc == KP_ACT_MOVE_RC_OFF) {
		shell_error(shell, "Actuator is off, stopping");
		return rc;
	}

	/* Stop, if changing the current position */
	if (ppos == NULL) {
		return 0;
	}

	/* Try to return to the start position */
	switch (kp_act_move_to(start_pos, kp_act_speed)) {
		case KP_ACT_MOVE_RC_OK:
			break;
		case KP_ACT_MOVE_RC_ABORTED:
			shell_warn(
				shell,
				"Moving back to the start position "
				"was aborted"
			);
			break;
		case KP_ACT_MOVE_RC_OFF:
			shell_warn(
				shell,
				"Couldn't move back to the start "
				"position - actuator is off"
			);
			break;
		default:
			shell_error(
				shell,
				"Unexpected error moving back to the "
				"start position"
			);
			break;
	}

	return 0;
}

SHELL_CMD_ARG_REGISTER(adjust, NULL,
		       "Adjust the \"current\" (default), \"top\", "
		       "or \"bottom\" actuator positions interactively",
		       kp_cmd_adjust, 1, 1);

/** Execute the "set speed <percentage>" command */
static int
kp_cmd_set_speed(const struct shell *shell, size_t argc, char **argv)
{
	long speed;

	assert(argc == 2);

	if (!kp_parse_non_negative_number(argv[1], &speed) || speed > 100) {
		shell_error(
			shell,
			"Invalid speed percentage (expecting 0-100): %s",
			argv[1]
		);
		return 1;
	}
	kp_act_speed = (uint32_t)speed;
	return 0;
}

/** Execute the "set top" command */
static int
kp_cmd_set_top(const struct shell *shell, size_t argc, char **argv)
{
	int32_t pos;
	ARG_UNUSED(argc);
	ARG_UNUSED(argv);
	pos = kp_act_locate();
	if (!kp_act_pos_is_valid(pos)) {
		shell_error(shell, "Actuator is off, position not set");
		return 1;
	}
	if (kp_act_pos_is_valid(kp_act_pos_bottom) &&
			pos >= kp_act_pos_bottom) {
		shell_error(shell, "Position not above bottom, not set");
		return 1;
	}
	kp_act_pos_top = pos;
	return 0;
}

/** Execute the "set bottom" command */
static int
kp_cmd_set_bottom(const struct shell *shell, size_t argc, char **argv)
{
	int32_t pos;
	ARG_UNUSED(argc);
	ARG_UNUSED(argv);
	pos = kp_act_locate();
	if (!kp_act_pos_is_valid(pos)) {
		shell_error(shell, "Actuator is off, position not set");
		return 1;
	}
	if (kp_act_pos_is_valid(kp_act_pos_top) &&
			pos <= kp_act_pos_top) {
		shell_error(shell, "Position not below top, not set");
		return 1;
	}
	kp_act_pos_bottom = pos;
	return 0;
}

/** Capture configuration */
static struct kp_cap_conf kp_cap_conf;

/** Execute the
 * "set ch <idx> none/up/down/both [rising/falling [<name>]]"
 * command */
static int
kp_cmd_set_ch(const struct shell *shell, size_t argc, char **argv)
{
	long idx;
	const char *arg;
	struct kp_cap_ch_conf conf;
	assert(argc >= 3);
	assert(argc <= 5);

	/* Parse channel index */
	arg = argv[1];
	if (!kp_parse_non_negative_number(arg, &idx) ||
			idx >= ARRAY_SIZE(kp_cap_conf.ch_list)) {
		shell_error(
			shell,
			"Invalid channel index (0-%zu expected): %s",
			ARRAY_SIZE(kp_cap_conf.ch_list) - 1,
			arg
		);
		return 1;
	}

	/* Read current state */
	conf = kp_cap_conf.ch_list[idx];

	/* Parse capture directions, if specified */
	if (argc >= 3) {
		arg = argv[2];
		if (!kp_cap_dirs_from_str(arg, &conf.dirs)) {
			shell_error(
				shell,
				"Invalid capture directions "
				"(none/up/down/both expected): %s",
				arg
			);
			return 1;
		}
	}

	/* Parse capture edge, if specified */
	if (argc >= 4) {
		arg = argv[3];
		if (kp_strcasecmp(arg, "rising") == 0) {
			conf.rising = true;
		} else if (kp_strcasecmp(arg, "falling") == 0) {
			conf.rising = false;
		} else {
			shell_error(
				shell,
				"Invalid capture edge "
				"(rising/falling expected): %s",
				arg
			);
			return 1;
		}
	}

	/* Read name, if specified */
	if (argc >= 5) {
		arg = argv[4];
		if (strlen(arg) >= sizeof(conf.name)) {
			shell_error(
				shell,
				"Channel name too long "
				"(%zu > %zu expected characters): %s",
				strlen(arg),
				sizeof(conf.name) - 1,
				arg
			);
			return 1;
		}
		strcpy(conf.name, arg);
	}

	/* Store the parameters */
	kp_cap_conf.ch_list[idx] = conf;

	return 0;
}

/** Execute the "set timeout <us>" command */
static int
kp_cmd_set_timeout(const struct shell *shell, size_t argc, char **argv)
{
	long timeout_us;

	assert(argc == 2);

	if (!kp_parse_non_negative_number(argv[1], &timeout_us)) {
		shell_error(shell, "Invalid timeout: %s", argv[1]);
		return 1;
	}
	if ((uint32_t)timeout_us + kp_cap_conf.bounce_us >=
	    KP_CAP_TIME_MAX_US) {
		shell_error(
			shell,
			"Timeout plus bounce time exceed "
			"maximum capture time: %ld + %u >= %u",
			timeout_us, kp_cap_conf.bounce_us, KP_CAP_TIME_MAX_US
		);
		return 1;
	};
	kp_cap_conf.timeout_us = (uint32_t)timeout_us;
	return 0;
}

/** Execute the "set bounce <us>" command */
static int
kp_cmd_set_bounce(const struct shell *shell, size_t argc, char **argv)
{
	long bounce_us;

	assert(argc == 2);

	if (!kp_parse_non_negative_number(argv[1], &bounce_us)) {
		shell_error(shell, "Invalid bounce time: %s", argv[1]);
		return 1;
	}
	if (kp_cap_conf.timeout_us + (uint32_t)bounce_us >=
	    KP_CAP_TIME_MAX_US) {
		shell_error(
			shell,
			"Bounce time plus timeout exceed "
			"maximum capture time: %ld + %u >= %u",
			bounce_us, kp_cap_conf.timeout_us, KP_CAP_TIME_MAX_US
		);
		return 1;
	};
	kp_cap_conf.bounce_us = (uint32_t)bounce_us;
	return 0;
}

SHELL_STATIC_SUBCMD_SET_CREATE(set_subcmds,
	SHELL_CMD_ARG(speed, NULL,
			"Set speed: <percentage>",
			kp_cmd_set_speed, 2, 0),
	SHELL_CMD(top, NULL, "Register current position as the top",
			kp_cmd_set_top),
	SHELL_CMD(bottom, NULL, "Register current position as the bottom",
			kp_cmd_set_bottom),
	SHELL_CMD_ARG(ch, NULL,
			"Set channel configuration: "
			"<idx> none/up/down/both [rising/falling [<name>]]",
			kp_cmd_set_ch, 3, 2),
	SHELL_CMD_ARG(timeout, NULL,
			"Set capture timeout: <us>",
			kp_cmd_set_timeout, 2, 0),
	SHELL_CMD_ARG(bounce, NULL,
			"Set bounce time: <us>",
			kp_cmd_set_bounce, 2, 0),
	SHELL_SUBCMD_SET_END
);

SHELL_CMD_REGISTER(set, &set_subcmds,
			"Set parameters", NULL);

/** Execute the "get speed" command */
static int
kp_cmd_get_speed(const struct shell *shell, size_t argc, char **argv)
{
	ARG_UNUSED(argc);
	ARG_UNUSED(argv);
	shell_print(shell, "%u%%", kp_act_speed);
	return 0;
}

/** Execute the "get top" command */
static int
kp_cmd_get_top(const struct shell *shell, size_t argc, char **argv)
{
	enum kp_act_move_rc rc;
	ARG_UNUSED(argc);
	ARG_UNUSED(argv);
	if (!kp_act_pos_is_valid(kp_act_pos_top)) {
		shell_error(shell, "Top position not set, not moving");
		return 1;
	}
	rc = kp_act_move_to(kp_act_pos_top, kp_act_speed);
	if (rc == KP_ACT_MOVE_RC_ABORTED) {
		shell_error(shell, "Aborted");
	} else if (rc == KP_ACT_MOVE_RC_OFF) {
		shell_error(shell, "Actuator is off, stopping");
	}
	return rc != KP_ACT_MOVE_RC_OK;
}

/** Execute the "get bottom" command */
static int
kp_cmd_get_bottom(const struct shell *shell, size_t argc, char **argv)
{
	enum kp_act_move_rc rc;
	ARG_UNUSED(argc);
	ARG_UNUSED(argv);
	if (!kp_act_pos_is_valid(kp_act_pos_bottom)) {
		shell_error(shell, "Bottom position not set, not moving");
		return 1;
	}
	rc = kp_act_move_to(kp_act_pos_bottom, kp_act_speed);
	if (rc == KP_ACT_MOVE_RC_ABORTED) {
		shell_error(shell, "Aborted");
	} else if (rc == KP_ACT_MOVE_RC_OFF) {
		shell_error(shell, "Actuator is off, stopping");
	}
	return rc != KP_ACT_MOVE_RC_OK;
}

/** Execute the "get ch <idx>" command */
static int
kp_cmd_get_ch(const struct shell *shell, size_t argc, char **argv)
{
	long idx;
	const char *arg;
	const struct kp_cap_ch_conf *conf;

	assert(argc == 2);

	/* Parse channel index */
	arg = argv[1];
	if (!kp_parse_non_negative_number(arg, &idx) ||
			idx >= ARRAY_SIZE(kp_cap_conf.ch_list)) {
		shell_error(
			shell,
			"Invalid channel index (0-%zu expected): %s",
			ARRAY_SIZE(kp_cap_conf.ch_list) - 1,
			arg
		);
		return 1;
	}

	/* Output channel configuration */
	conf = &kp_cap_conf.ch_list[idx];
	shell_print(shell, "%s %s %s",
			kp_cap_dirs_to_lcstr(conf->dirs),
			(conf->rising ? "rising" : "falling"),
			conf->name);
	return 0;
}

/** Execute the "get timeout" command */
static int
kp_cmd_get_timeout(const struct shell *shell, size_t argc, char **argv)
{
	ARG_UNUSED(argc);
	ARG_UNUSED(argv);
	shell_print(shell, "%u us", kp_cap_conf.timeout_us);
	return 0;
}

/** Execute the "get bounce" command */
static int
kp_cmd_get_bounce(const struct shell *shell, size_t argc, char **argv)
{
	ARG_UNUSED(argc);
	ARG_UNUSED(argv);
	shell_print(shell, "%u us", kp_cap_conf.bounce_us);
	return 0;
}

SHELL_STATIC_SUBCMD_SET_CREATE(get_subcmds,
	SHELL_CMD(speed, NULL,
			"Get speed percentage",
			kp_cmd_get_speed),
	SHELL_CMD(top, NULL, "Restore the top position",
			kp_cmd_get_top),
	SHELL_CMD(bottom, NULL, "Restore the bottom position",
			kp_cmd_get_bottom),
	SHELL_CMD_ARG(ch, NULL,
			"Get channel configuration: "
			"<idx> -> none/up/down/both rising/falling <name>",
			kp_cmd_get_ch, 2, 0),
	SHELL_CMD(timeout, NULL,
			"Get capture timeout, us",
			kp_cmd_get_timeout),
	SHELL_CMD(bounce, NULL,
			"Get bounce time, us",
			kp_cmd_get_bounce),
	SHELL_SUBCMD_SET_END
);

SHELL_CMD_REGISTER(get, &get_subcmds,
			"Get parameters", NULL);
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
void
main(void)
{
	const struct device *dev;
	size_t i;

	/* Check shell UART is ready */
	dev = DEVICE_DT_GET(DT_CHOSEN(zephyr_shell_uart));
	if (!device_is_ready(dev)) {
		return;
	}

	/* Initialize the shell extensions */
	kp_shell_init();

	/*
	 * Initialize GPIO pins
	 */
	if (!device_is_ready(kp_act_gpio)) {
		return;
	}
	if (!device_is_ready(kp_dbg_gpio)) {
		return;
	}
	gpio_pin_configure(kp_dbg_gpio, kp_dbg_pin_update,
				GPIO_PUSH_PULL | GPIO_OUTPUT_LOW);

	/*
	 * Initialize the actuator
	 */
	kp_act_init(kp_act_gpio, /* disable */ 3, /* dir */ 8, /* step */ 9);

	/*
	 * Set default capture configuration
	 */
	kp_cap_conf.timeout_us = 1000000;
	kp_cap_conf.bounce_us = 50000;
	for (i = 0; i < ARRAY_SIZE(kp_cap_conf.ch_list); i++) {
		kp_cap_conf.ch_list[i] = (struct kp_cap_ch_conf){
			.dirs = KP_CAP_DIRS_NONE,
			.rising = true,
			.name = {0},
		};
	}

	/*
	 * Configure capturer debug output
	 */
	struct kp_cap_dbg_conf cap_dbg_conf = {
		.gpio = kp_dbg_gpio,
		.update_pin = kp_dbg_pin_update,
	};
	for (i = 0; i < ARRAY_SIZE(cap_dbg_conf.cap_pin_list); i++) {
		gpio_pin_configure(cap_dbg_conf.gpio, kp_dbg_pin_ch_base + i,
					GPIO_PUSH_PULL | GPIO_OUTPUT_LOW);
		cap_dbg_conf.cap_pin_list[i] = kp_dbg_pin_ch_base + i;
	}

	/*
	 * Initialize the capturer
	 */
	const struct device *clk = DEVICE_DT_GET(STM32_CLOCK_CONTROL_NODE);
	struct stm32_pclken pclken = {
		.bus = DT_CLOCKS_CELL(KP_TIMER_NODE, bus),
		.enr = DT_CLOCKS_CELL(KP_TIMER_NODE, bits)
	};
	if (!device_is_ready(clk)) {
		return;
	}
	if (clock_control_on(clk, (clock_control_subsys_t *)&pclken) < 0) {
		return;
	}
	IRQ_CONNECT(DT_IRQ_BY_NAME(KP_TIMER_NODE, trgcom, irq),
		    DT_IRQ_BY_NAME(KP_TIMER_NODE, trgcom, priority),
		    kp_cap_isr, NULL, 0);
	irq_enable(DT_IRQ_BY_NAME(KP_TIMER_NODE, trgcom, irq));
	IRQ_CONNECT(DT_IRQ_BY_NAME(KP_TIMER_NODE, up, irq),
		    DT_IRQ_BY_NAME(KP_TIMER_NODE, up, priority),
		    kp_cap_isr, NULL, 0);
	irq_enable(DT_IRQ_BY_NAME(KP_TIMER_NODE, up, irq));
	IRQ_CONNECT(DT_IRQ_BY_NAME(KP_TIMER_NODE, cc, irq),
		    DT_IRQ_BY_NAME(KP_TIMER_NODE, cc, priority),
		    kp_cap_isr, NULL, 0);
	irq_enable(DT_IRQ_BY_NAME(KP_TIMER_NODE, cc, irq));
	kp_cap_init((TIM_TypeDef *)DT_REG_ADDR(KP_TIMER_NODE), &cap_dbg_conf);
}

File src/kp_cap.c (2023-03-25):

/** @file
 *  @brief Keypecker capturer
 */

/*
 * Copyright (c) 2022 Nikolai Kondrashov
 *
 * SPDX-License-Identifier: GPL-2.0-or-later
 */

#include "kp_cap.h"
#include "kp_misc.h"
#include <string.h>

/** Masks for the channels available for capture */
static const uint32_t kp_cap_ch_mask_list[KP_CAP_CH_NUM] = {
	LL_TIM_CHANNEL_CH2,
	LL_TIM_CHANNEL_CH3,
};

/** Capture interrupt-enabling/interrupt-flag masks for each channel */
/* NOTE: Assuming SR bits match DIER bits */
static const uint32_t kp_cap_ch_ccif_mask_list[KP_CAP_CH_NUM] = {
	TIM_SR_CC2IF,
	TIM_SR_CC3IF,
};

/** Overcapture flag masks for each channel */
static const uint32_t kp_cap_ch_ccof_mask_list[KP_CAP_CH_NUM] = {
	TIM_SR_CC2OF,
	TIM_SR_CC3OF,
};

/** Offset of the captured-value register for each channel, bytes */
static const size_t kp_cap_ch_ccr_offset_list[KP_CAP_CH_NUM] = {
	offsetof(TIM_TypeDef, CCR2),
	offsetof(TIM_TypeDef, CCR3),
};

/** The timer to use for capture */
static TIM_TypeDef* kp_cap_timer = NULL;

/** Debugg output configuration */
struct kp_cap_dbg_conf kp_cap_dbg_conf;

/** The semaphore signaling a capture can be started */
static K_SEM_DEFINE(kp_cap_available, 1, 1);

/** The capture interrupt mask for all channels to be captured */
static uint32_t kp_cap_ch_ccif_mask;

/** The maximum number of ticks to await capture of all channels */
static uint32_t kp_cap_timeout_ticks;

/** The minimum number of ticks to wait for a channel to bounce */
static uint32_t kp_cap_bounce_ticks;

/** The capture abort flag */
static volatile bool kp_cap_aborted;

/** The semaphore signaling a capture is done */
static K_SEM_DEFINE(kp_cap_done, 0, 1);

/** The interrupt state spinlock */
/** Only needs to be held if kp_cap_available is taken */
static struct k_spinlock kp_cap_lock = {};

void
kp_cap_isr(void *arg)
{
	static const struct kp_cap_dbg_conf *dbg = &kp_cap_dbg_conf;
	bool done = false;
	k_spinlock_key_t key;
	size_t i;

	assert(kp_cap_is_initialized());

	key = k_spin_lock(&kp_cap_lock);

	/* If the capture is not aborted */
	if (!kp_cap_aborted) {
		uint32_t sr = kp_cap_timer->SR;
		uint32_t masked_sr = sr & kp_cap_timer->DIER;
		/* If the timer got triggered */
		if (masked_sr & TIM_SR_TIF) {
			/* Raise the debugging pins, if any */
			if (dbg->gpio && dbg->update_pin != UINT8_MAX) {
				gpio_pin_set(dbg->gpio, dbg->update_pin, 1);
			}
			for (i = 0; dbg->gpio && i < KP_CAP_CH_NUM; i++) {
				if (dbg->cap_pin_list[i] != UINT8_MAX) {
					gpio_pin_set(
						dbg->gpio,
						dbg->cap_pin_list[i],
						1
					);
				}
			}
			/* Clear the interrupt flag */
			kp_cap_timer->DIER &= ~TIM_SR_TIF;
			kp_cap_timer->SR &= ~TIM_SR_TIF;
		/* Else, If both the capture and bounce times have expired */
		} else if (masked_sr & TIM_SR_UIF) {
			/* Disable the trigger */
			LL_TIM_SetSlaveMode(kp_cap_timer,
						LL_TIM_SLAVEMODE_DISABLED);
			/* Stop the timer */
			LL_TIM_DisableCounter(kp_cap_timer);
			/* Disable all the interrupts */
			kp_cap_timer->DIER = 0;
			/* Lower the debugging pin, if any */
			if (dbg->gpio && dbg->update_pin != UINT8_MAX) {
				gpio_pin_set(dbg->gpio, dbg->update_pin, 0);
			}
			/* Prepare to signal the capture is done */
			done = true;
		} else {
			uint32_t ccif_mask = sr & kp_cap_ch_ccif_mask;
			uint32_t new_ccif_mask = ccif_mask & kp_cap_timer->DIER;

			/* Lower debugging GPIO pins, if specified */
			for (i = 0; dbg->gpio && i < KP_CAP_CH_NUM; i++) {
				if (dbg->cap_pin_list[i] != UINT8_MAX &&
				    (kp_cap_ch_ccif_mask_list[i] &
				     new_ccif_mask)) {
					gpio_pin_set(
						dbg->gpio,
						dbg->cap_pin_list[i],
						0
					);
				}
			}

			/* If all channels were captured (but may bounce) */
			if (ccif_mask == kp_cap_ch_ccif_mask) {
				/* Shorten the capture, if possible */
				LL_TIM_DisableCounter(kp_cap_timer);
				if ((uint32_t)kp_cap_timer->CNT <
						kp_cap_timeout_ticks) {
					LL_TIM_SetAutoReload(
						kp_cap_timer,
						kp_cap_timer->CNT +
						kp_cap_bounce_ticks
					);
				}
				LL_TIM_EnableCounter(kp_cap_timer);
			}

			/* Disable the interrupts we've processed */
			kp_cap_timer->DIER &= ~ccif_mask;
		}
	}

	k_spin_unlock(&kp_cap_lock, key);

	if (done) {
		/* Signal the capture is done */
		k_sem_give(&kp_cap_done);
	}
}

size_t
kp_cap_conf_ch_num(const struct kp_cap_conf *conf, enum kp_cap_dirs dirs)
{
	size_t i;
	size_t dir_ch_num;
	assert(kp_cap_conf_is_valid(conf));
	assert(kp_cap_dirs_is_valid(dirs));
	for (dir_ch_num = 0, i = 0; i < ARRAY_SIZE(conf->ch_list); i++) {
		if (conf->ch_list[i].dirs & dirs) {
			dir_ch_num++;
		}
	}
	return dir_ch_num;
}

size_t
kp_cap_conf_ch_res_idx(const struct kp_cap_conf *conf, bool even_down,
		       size_t pass, size_t ch)
{
	const bool odd_pass = pass & 1;
	/* Number of channel results per round (two passes) */
	size_t round_ch_res_num = 0;
	/* Channel result index in this pass */
	size_t pass_ch_res_idx = 0;
	size_t i;

	assert(kp_cap_conf_is_valid(conf));
	assert((even_down & 1) == even_down);
	assert(ch < ARRAY_SIZE(conf->ch_list));

	for (i = 0; i < ARRAY_SIZE(conf->ch_list); i++) {
		enum kp_cap_dirs dirs = conf->ch_list[i].dirs;

		if (dirs & KP_CAP_DIRS_UP) {
			round_ch_res_num++;
		}
		if (dirs & KP_CAP_DIRS_DOWN) {
			round_ch_res_num++;
		}
		/* If this is an odd pass */
		if (odd_pass) {
			/*
			 * If the channel is enabled in the previous
			 * (even) pass
			 */
			if (dirs & kp_cap_dirs_from_down(even_down)) {
				pass_ch_res_idx++;
			}
		}
		/* If the channel is enabled in this pass */
		if (i < ch &&
		    (dirs & kp_cap_dirs_from_down(even_down ^ odd_pass))) {
			pass_ch_res_idx++;
		}
	}
	return round_ch_res_num * (pass >> 1) + pass_ch_res_idx;
}
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

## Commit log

2022-08-12 Add first working mechanical model
    [keypecker.FCStd]
2022-08-12 Fix Zephyr include paths
    [kp.c]
2022-09-26 Fix kp.c documentation comment
    [kp.c]
2022-10-31 Implement basic actuator control shell commands
2022-10-31 Do not overwrite move failure on abortion
    [kp.c]
2022-11-12 Check args/conditions before bypassing
    Check for argument and condition correctness in shell commands before
    installing the input bypass to avoid unnecessary ugly prompt artefacts
    if they fail.
    Check for power in the adjust command to not require input before
    failing due to the absence of power.
    [kp.c]
2022-11-27 Disable PWM1 peripheral as unused
2022-12-25 act: Remove notion of power for simplicity
2022-12-26 act: Switch to state spinlock for use with IRQ
2022-12-26 Support configuring actuator speed
2022-12-30 Add "tighten" command
2023-01-06 Fix parsing tighten passes, foolproof the code
    [kp.c]
2023-01-14 Avoid division by zero when scaling histograms
    [kp.c]
2023-01-14 Support directional capture channels
    Support enabling capture channels for specific movement directions: up,
    down, or both. This allows having channels connected directly to a
    hardware switch. Switches have one edge for pressing down and another
    for releasing, and the channels would time out if they expected the edge
    on each movement.
2023-01-14 Switch shell and console from USB to USART1
    Switch both the shell and the console from USB to USART1 from easier
    development (no need to reconnect USB cable on reset), simpler power
    supply circuitry (USB can't supply power now), to free TIM1 channel
    four, and to have more RAM.
    Use remapped USART1 pins to avoid clashing with TIM1 channels 2 and 3.
    [kp.c]
2023-01-14 Use minimum histogram step size to avoid div-by-0
    [kp.c]
2023-01-15 Check for enabled channels in check and tighten
    [kp.c]
2023-01-15 act: Slow down on turns to avoid skips
    [kp_act.c]
2023-01-21 Remove configuration of unused "trigger" pin
2023-01-21 Clarify the GPIO port belongs to the actuator
2023-01-21 Output capture interrupt status on GPIO pins
2023-01-21 cap: Wait for timeout+bounce even without channels
    Wait for a full timeout plus bounce times when capturing, even with all
    channels disabled. This prevents accidental capture of bounce of the
    previous movement as the trigger of the current movement.
    [kp_cap.c]
2023-01-22 cap: Invert debugging pin polarity to see duration
    [kp_cap.c]
2023-01-22 Use a constant for the base debug pin number
2023-01-22 cap: Fix a variable reference in debug pin list docs
    [kp_cap.c]
2023-01-22 cap: Add support for update pin debugging
2023-01-22 cap: Raise debugging pins on trigger interrupt
2023-02-25 Switch to packed result storage and more
    Remove the KP_CAP_CH_STATUS_DISABLED, and instead check the channel
    configuration and capture direction to figure out if the channel is
    disabled, or not. This allows packed result storage, as uncaptured
    channels don't need to be stored.
    Switch to supplying a configuration structure, instead of separate
    parameters to kp_cap_start(). This way the call is not so messy and we
    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
2023-02-25 cap: Switch to passing all debug conf to init
2023-02-26 cap: Fix result number calculation
    [kp_cap.c]
2023-03-11 cap: Avoid reacting to disabled interrupt flags
    Avoid reacting to status flags corresponding to disabled interrupts,
    which seemingly can be raised regardless of interrupt status.
    [kp_cap.c]
2023-03-11 cap: Fix a comment
    [kp_cap.c]
2023-03-11 sample: Capture always
    Always run the capture in kp_sample(), with its associated timeouts, to
    make sure we consume any possible capture triggers and they don't affect
    another sample.
2023-03-11 Extract measurement into a module
    Extract measurement acquiring and printing into a new module: "kp_meas".
    Separate acquiring and printing functions.
2023-03-11 cap: Disable ARR preloading
    Disable timer auto-reload register preloading, so we don't have to
    generate an update event to update it, and the first capture gets
    the correct specified timeout.
    [kp_cap.c]
2023-03-18 meas: Print mean between min and max
2023-03-18 Fix documented default of tighten passes
    [kp.c]
2023-03-18 Support acquiring/printing measurements separately
2023-03-18 Support limiting actuator adjustment range
2023-03-25 Report errors when measuring
    [kp.c]
2023-03-25 cap: Fix capturing multiple channels per pass
    Use the value of SR register not masked with the interrupt-enable flags
    for determining if all channels have captured, in the capture ISR.
    Otherwise we never notice that all channels have captured, as each is
    interrupt-masked after detection.
    This fixes capturing multiple channels per pass.
    [kp_cap.c]
